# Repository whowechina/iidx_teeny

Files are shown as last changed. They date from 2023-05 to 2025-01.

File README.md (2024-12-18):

# Teeny IIDX - Beatmania IIDX controller

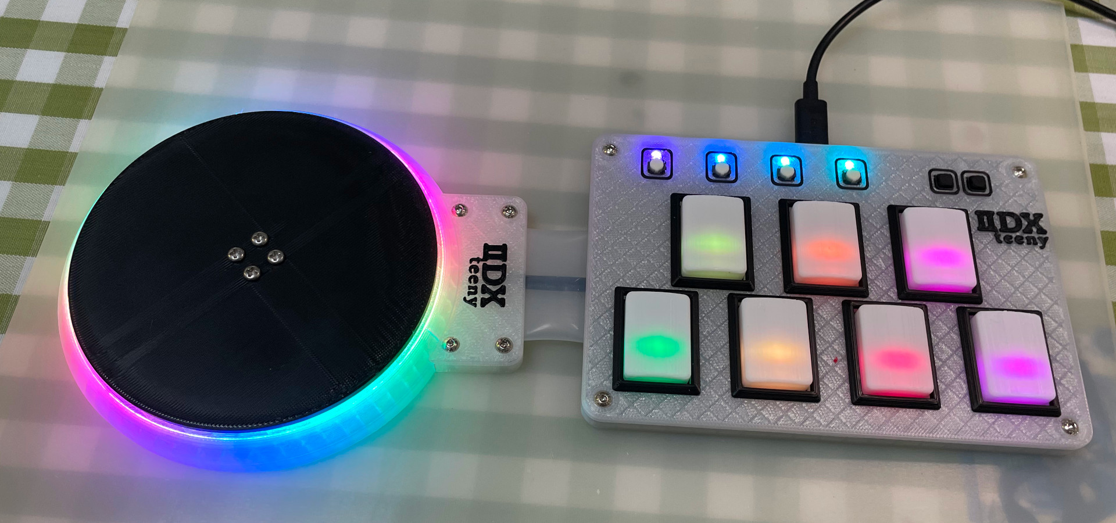
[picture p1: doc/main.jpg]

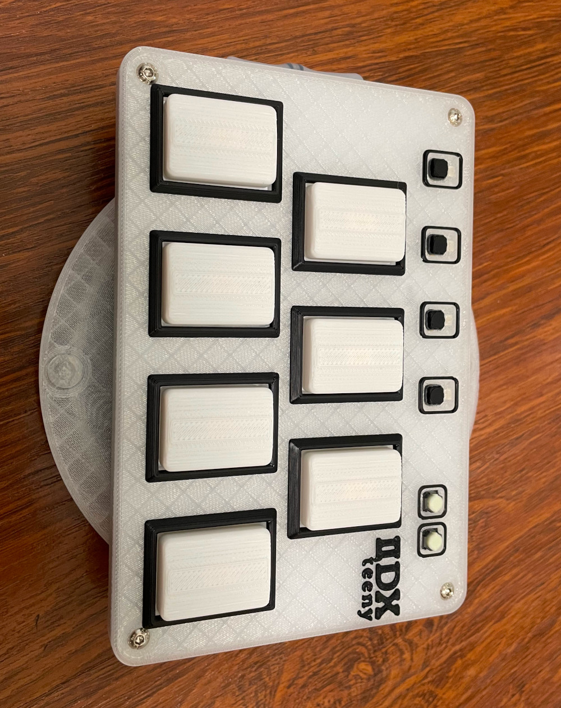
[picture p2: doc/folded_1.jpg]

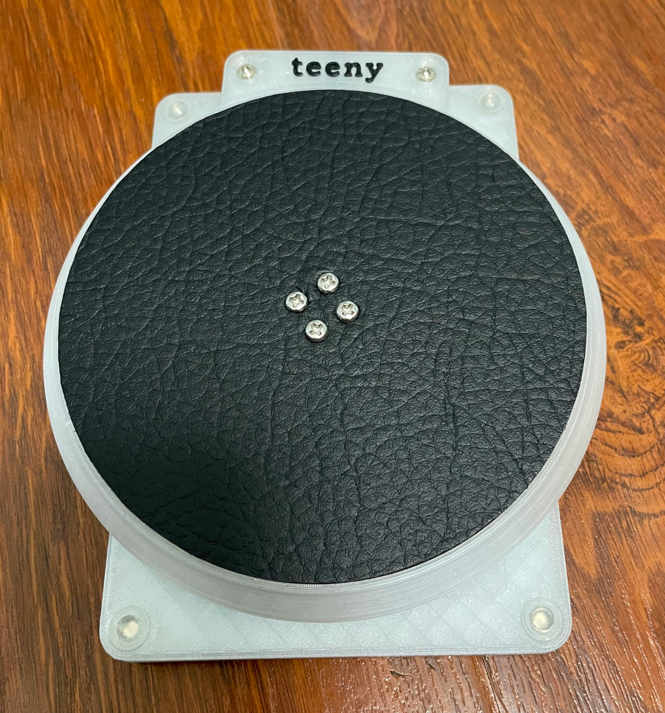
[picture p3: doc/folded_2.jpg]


# IMPORTANT NOTE
After a major refactor, I've merged this "IIDX Teeny" repository into the "IIDX Pico" repository and will no longer update this repository. Please refer to the "IIDX Pico" repository for guides and the latest updates.

https://github.com/whowechina/iidx_pico

This is the a small brother of my previous Pico IIDX controller. Both Pico IIDX and this Teeny IIDX share the same firmware which is in Pico IIDX repo.
<https://github.com/whowechina/iidx_pico>

Here's me playing Konami's Beatmania IIDX ultimate mobile with it. Yes, I'm a cat lover.
https://github.com/whowechina/iidx_teeny/assets/11623830/5aea28e7-6961-4d22-b5de-0fad74cdeacf

Features:
* It's thin, really really thin and foldable.
* HID lights, of course!
* Multiple turntable effects.
* Many live settings.
* All source files open.
* It's easier and more portable than IIDX Pico.

Thanks to many respectful guys/companies who made their tools or materials free or open source (KiCad, OpenSCAD, InkScape, Raspberry things). And also:
* RP_Silicon_KiCad: https://github.com/HeadBoffin/RP_Silicon_KiCad
* Switch_Keyboard_Kailh: https://github.com/kiswitch/keyswitch-kicad-library
* Type-C: https://github.com/ai03-2725/Type-C.pretty

## Notes
This project heavily relies on 3D printing, and skills to solder tiny components and thin cables.

## My Other Projects
You can check out my other cool projects.

         

* Popn Pico: https://github.com/whowechina/popn_pico
* IIDX Pico: https://github.com/whowechina/iidx_pico
* IIDX Teeny: https://github.com/whowechina/iidx_teeny
* Chu Pico: https://github.com/whowechina/chu_pico
* Mai Pico: https://github.com/whowechina/mai_pico
* Diva Pico: https://github.com/whowechina/diva_pico
* AIC Pico: https://github.com/whowechina/aic_pico
* Groove Pico: https://github.com/whowechina/groove_pico
* Geki Pico: https://github.com/whowechina/geki_pico
* Musec Pico: https://github.com/whowechina/musec_pico

## **Disclaimer** ##
I made this project in my personal time with no financial benefit or sponsorship. I will continue to improve the project. I have done my best to ensure that everything is accurate and functional, there's always a chance that mistakes may occur. I cannot be held responsible for any loss of your time or money that may result from using this open source project. Thank you for your understanding.

## About the License
It's CC-NC. So DIY for yourself and for your friend, don't make money from it. And plagiarism that doesn’t even dare to mention the original author is not acceptable. Plase note that pooling orders and group buying for raw materials is acceptable. Selling off any leftover components without profit is also acceptable.

If you're interested in some kind of commercial use, please contact me (Discord, QQ group, Wechat group or leave your contact in issue section).

## My Discord Invitation
https://discord.gg/M8f2PPQFEA

## HOW TO BUILD
### Turntable Materials
* 1x AS5600 hall angular sensor board set (23mm\*23mm)  
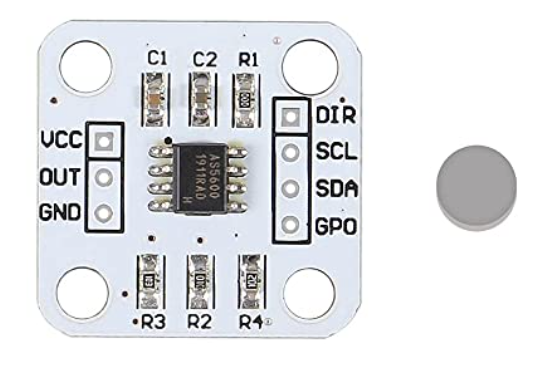
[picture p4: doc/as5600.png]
  
* 1x 6mm\*2mm magnet (must be radially magnetized), normally comes with the AS5600 board set, you can use one with different size of course, but you need to modify the 3D file.
* 1x 61804-2RS deep groove ball bearing (20x32x7mm), normally < 5US$;
* 1x WS2812B LED ring board, or RGB LED strip (recommended). Choose ones with dense LED arrangement (better if >=24 LEDs per board, or >90 LEDS per meter for LED strip);
* 6x M3*6mm screws (large flat head is better) and hex nuts.
* Non slip self-adhesive silicon pads (7-8mm diameter, also for Keyboard).  

### Keyboard Materials
* 1x Raspberry Pi Pico or Pi Pico W (if you need Bluetooth support).  
  https://www.raspberrypi.com/products/raspberry-pi-pico
* 7x Kailh Choc v1 key switches, to get better play feel, 7 of them should be linear (35gf to 50gf).  
  https://www.kailhswitch.com/mechanical-keyboard-switches/low-profile-key-switches/burnt-orange-switch.html  
* 6x Panasonic 6mm square tactile switch EVQP1K05M or a similar Alps one.  
  https://www3.panasonic.biz/ac/e/dl/catalog/index.jsp?series_cd=3473&part_no=EVQP1K05M
* 1x USB Type-C socket (918-418K2023S40001 or KH-TYPE-C-16P)
* 18x WS2812B-3528 RGB LEDs to light up the keys.
* 2x 0603 5.1kohm resistors for USB, (R20, R21).
* 2x 0603 0~20ohm resistors for light signals (R1, R2).
* 2x 0603 1-10kohm resistors for I2C pullup (R3, R4).
* 5x 0805 or 0603, 0.1 to 1uF capacitors.
* 4x M3*6mm screws and hex nuts to fix parts together.

### Connection for Foldable
* 2x silicon shielded cables with 4 core cables (about 25cm each), one for the RGB LEDs and one for the sensor.
* 1x silicon tube, outer diameter 27mm, inner diameter 25mm, so the wall thickness is 1mm.

### Step 1 - Buy
* Keyboard PCB  
  Just go [JLC](https://jlcpcb.com/) and make the order. Make sure the board thickness is **1.2mm**, it's very very important!

### Step 2 - 3D Print
#### Keyboard
Print with PLA transparent materials, 0.2mm layer, 4 walls, using 0.4mm nozzle.
* PCB bottom (teeny_bottom_P1|P2.stl, choose one according to your 1P or 2P choice).
* PCB top (teeny_top.stl)  
  Bambu Lab's AMS system is highly recommended, use PLA black for 3.0mm+ layers. So you'll have cool looking logo and key frames.

#### Turntable 
Again, print with 0.2mm layer, using 0.4mm nozzle, 5 walls. "Seam Position" should be set to "**Random**" in your slicer, not only it looks better, it makes the bearing-flange coupling smoother and tension distributed more evenly.  

* Base (teeny_tt.stl), PLA transparent.
* Bearing seat (teeny_bearing.stl), 20-60% fill, PLA white.
* Flange for disc (teeny_shaft.stl), 60% fill, PLA white.
* The disc (teeny_disc.stl), 60% fill, all fill patterns should be set to "Concentric".

#### Button keycaps  
* Print upside down, with easy-to-remove support materials.  
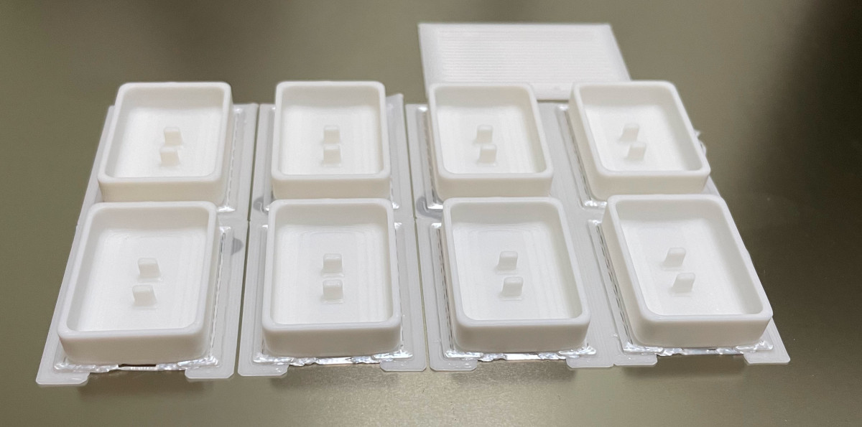
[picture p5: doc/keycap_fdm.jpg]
  

### Other Steps
It's similar to my previous Pico IIDX project, just read the documentation there.
<https://github.com/whowechina/iidx_pico>

But there're something you need to pay attention:
* On Teeny's PCB, there are 2 sets of soldering pads, 1 set is for AS5600, the other is for the WS2812 LED ring.
  * J1 is for LED, 5V is the power, L is LED signal, G is ground.
  * J2 is for AS5600, 3V is the power (actually 3.3V), S is I2C SCL, D is I2C SDA, G is ground.
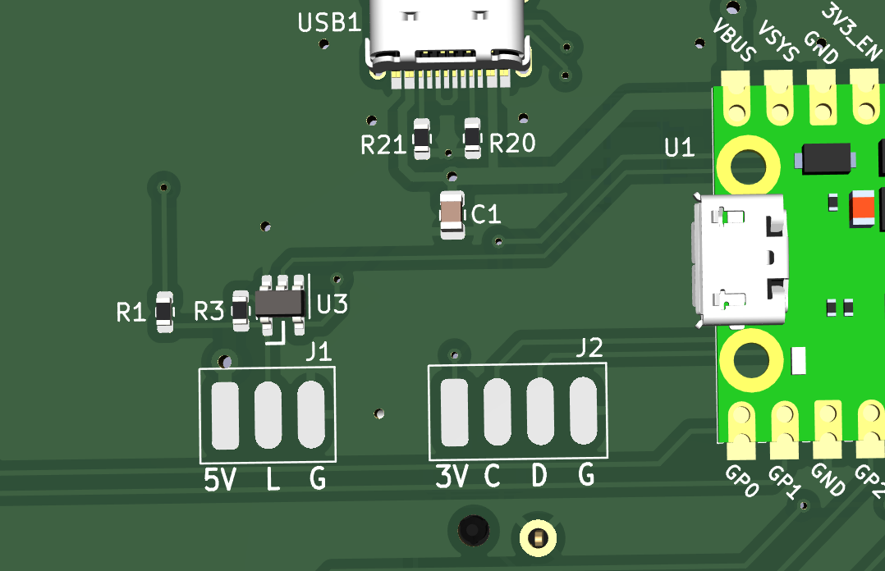
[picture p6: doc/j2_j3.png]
  
  * Please use two seperate cables to wire LED and AS5600, both (or at least one) should be shielded to prevent crosstalk interference.
  * Choose thin/soft cables, so they can fit. Get ultra thin USB cable or extract daughter cables from abandoned HDMI cables. 2mm diameter is the best.
  * R3, R4 are optional, if turntable (I2C) is not working properly, you may try use them.
  * There's a nice manual in IIDX Pico's repo, under doc folder. Follow the manual to set AS5600 to I2C mode and then do your LED ring setup.  
  <https://github.com/whowechina/iidx_pico/tree/main/doc/Firmware_manual.pdf>
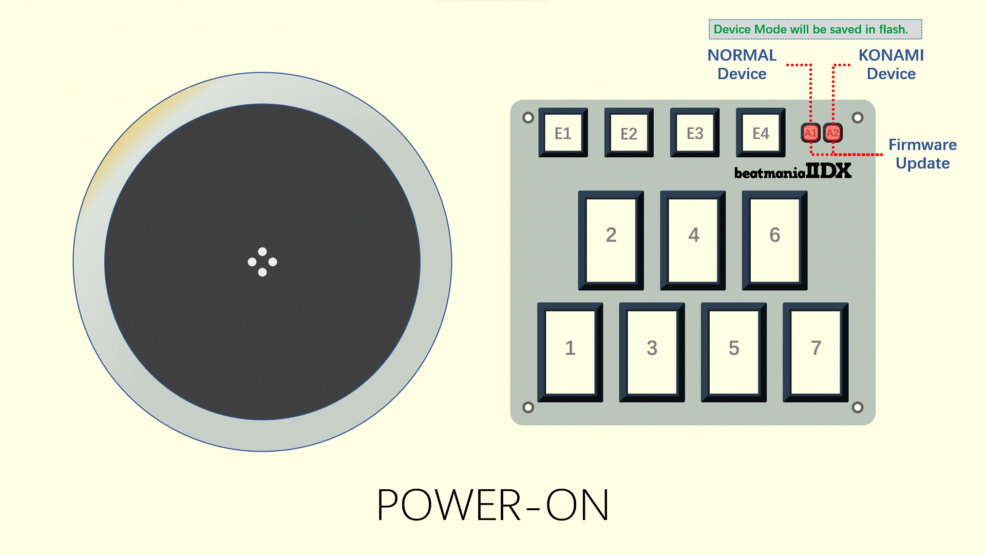
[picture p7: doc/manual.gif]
  

#### About the License
It's CC-NC. So diy for yourself and for your friend, don't make money from it.

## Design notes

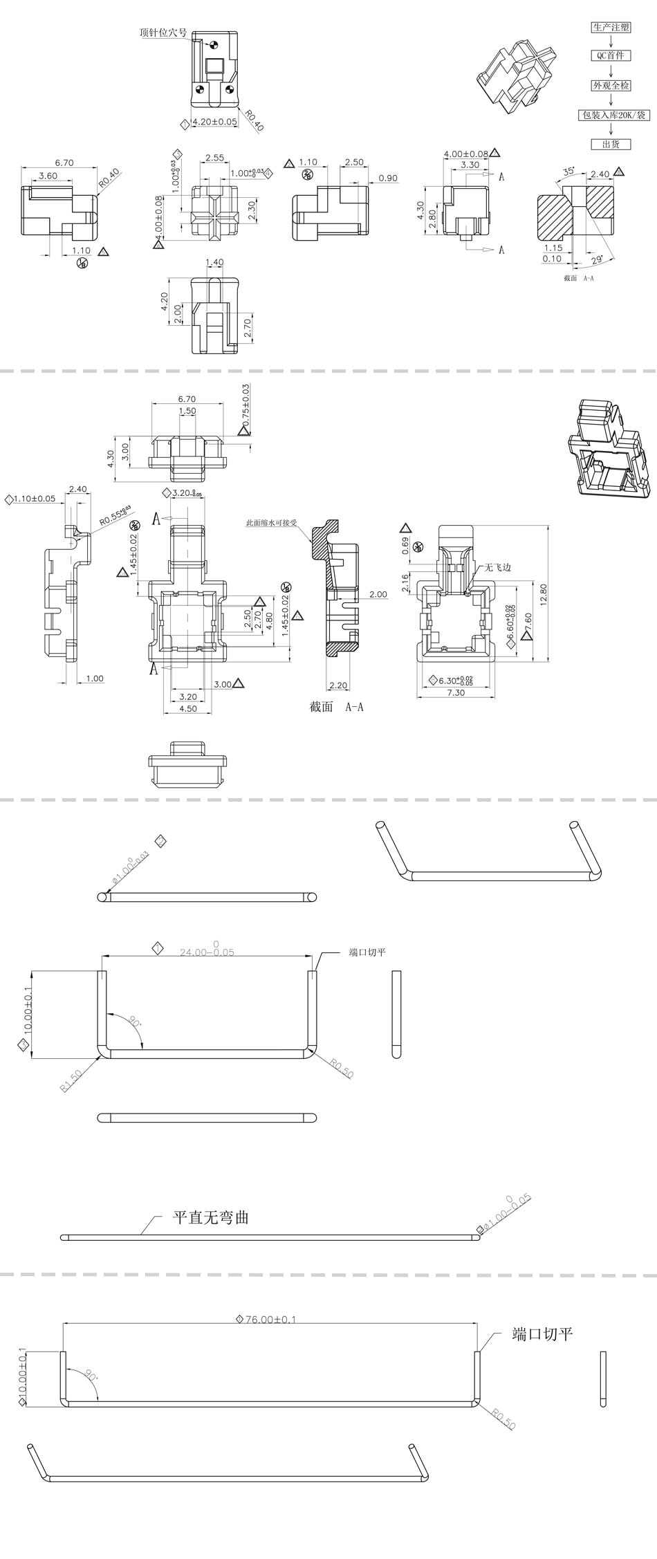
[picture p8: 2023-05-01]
cad/kailh-choc-stibilizer-4.jpg

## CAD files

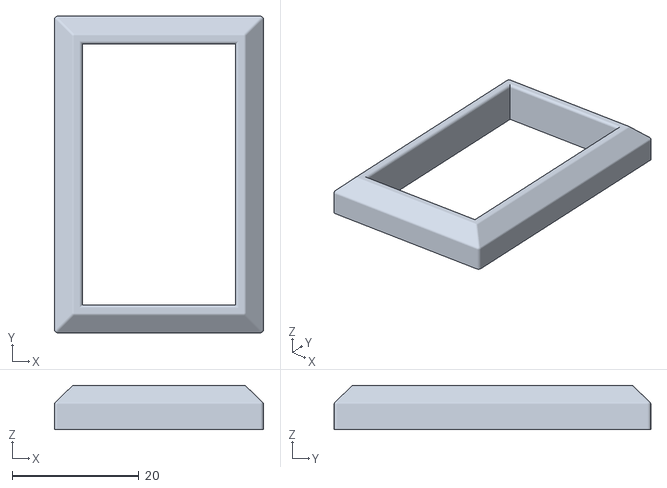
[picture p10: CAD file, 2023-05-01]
cad/keycap_frame_main.stl
33.0 x 50.0 x 7.00

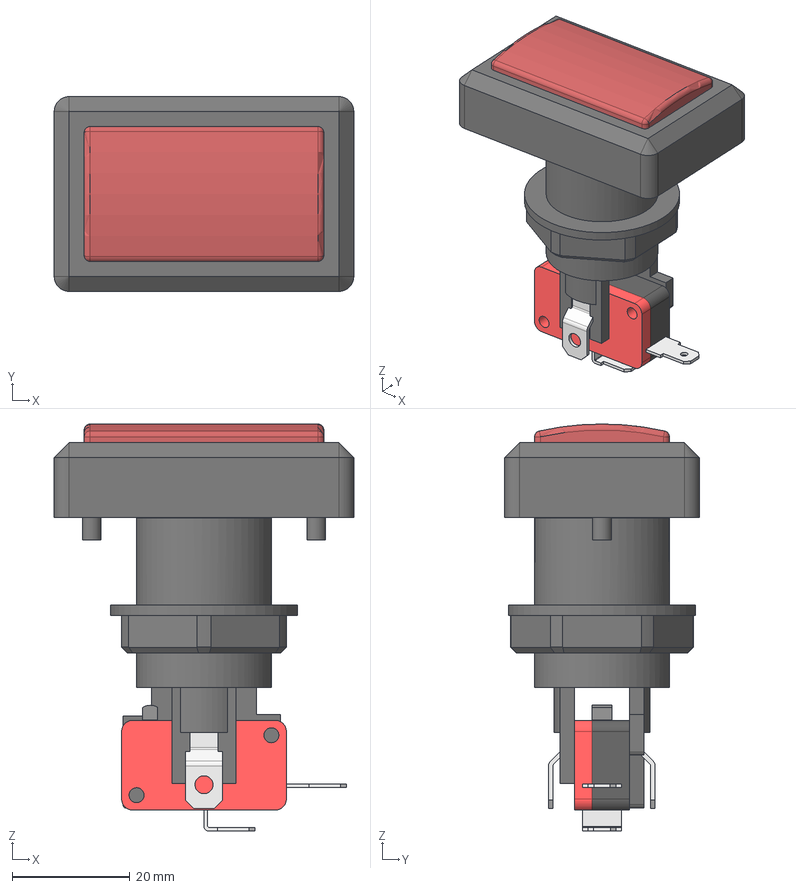
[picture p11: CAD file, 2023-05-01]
PCB/Keyboard/3dmodels/Credit Button Assy (Groovy).step
50.8 x 33.0 x 69.0 mm
Button
Nut
Switch

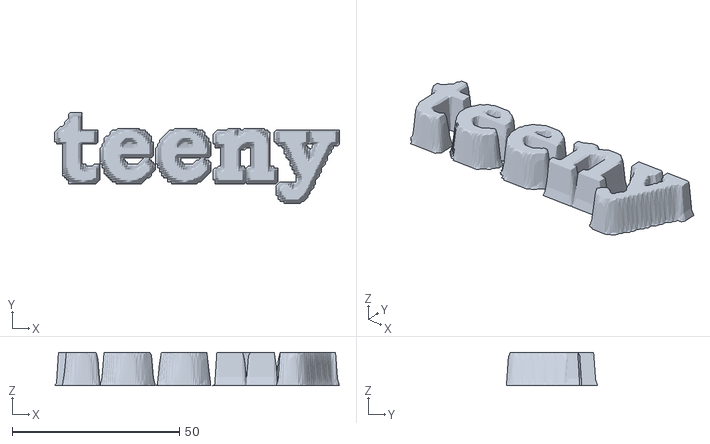
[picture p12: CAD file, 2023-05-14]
cad/teeny_only_logo.stl
85.2 x 27.3 x 10.0

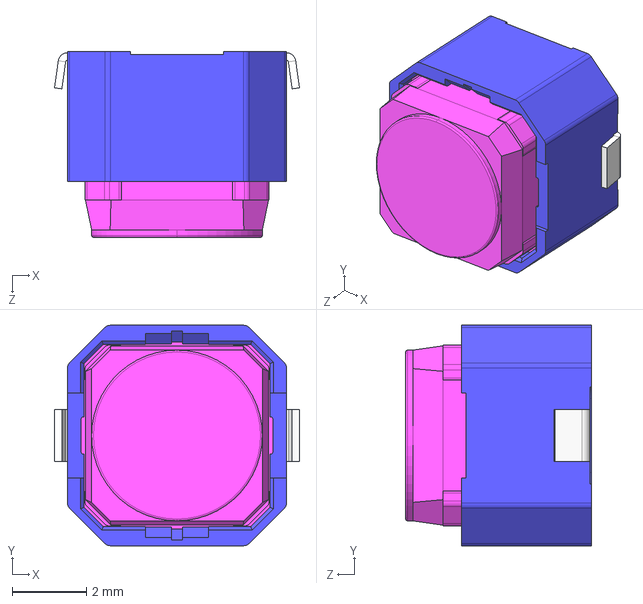
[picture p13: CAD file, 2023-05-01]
PCB/Keyboard/3dmodels/SKPMAM.STEP
6.60 x 5.94 x 5.00 mm

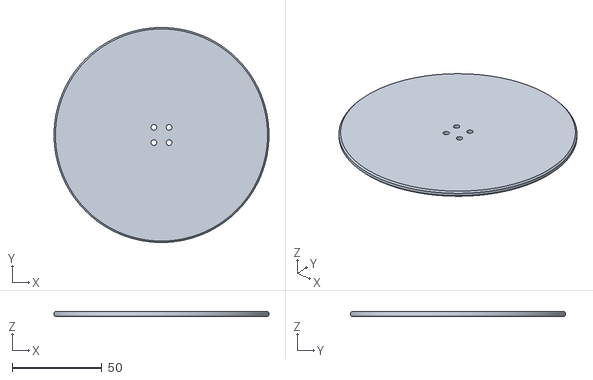
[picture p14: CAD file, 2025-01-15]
Production/3DPrint/Turntable Teeny - Disc.stl
120.0 x 120.0 x 3.00

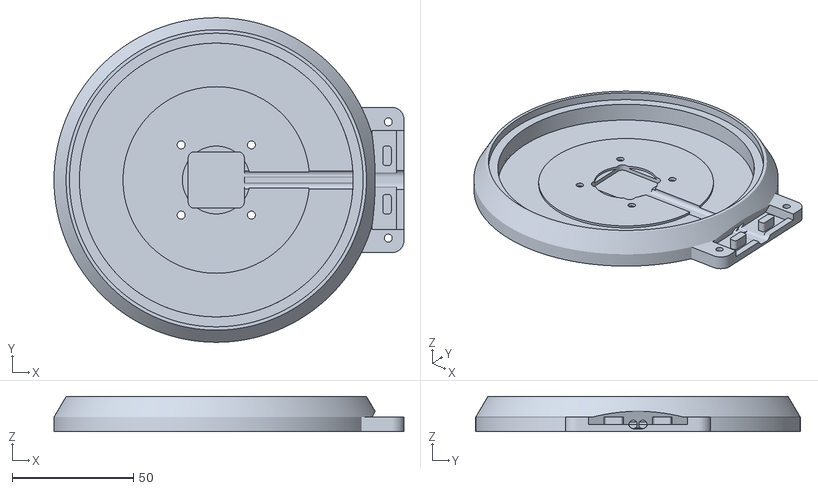
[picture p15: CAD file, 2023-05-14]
cad/teeny_tt.stl
144.5 x 134.0 x 14.5

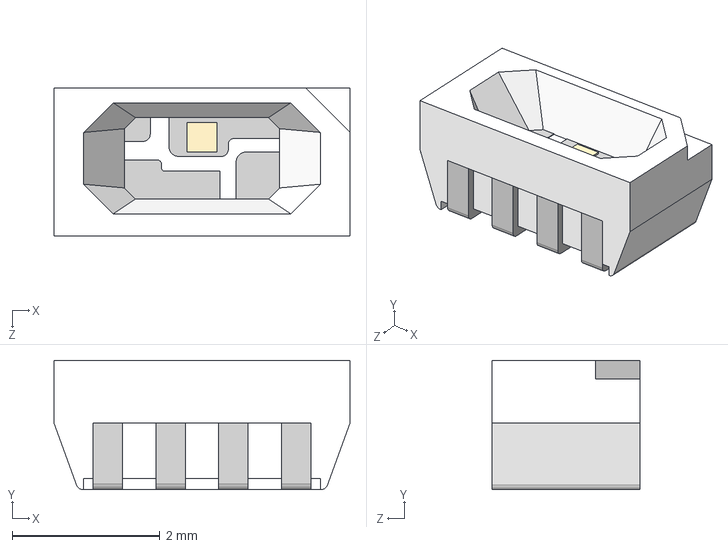
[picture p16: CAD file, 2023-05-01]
PCB/Keyboard/3dmodels/User Library-WS2812-4020.step
4.00 x 1.75 x 2.00 mm

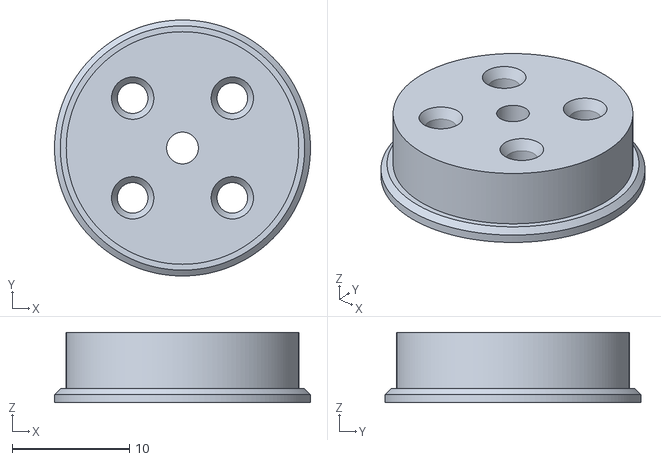
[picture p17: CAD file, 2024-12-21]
Production/3DPrint/Turntable - Magnet Seat.stl
21.8 x 21.8 x 6.00

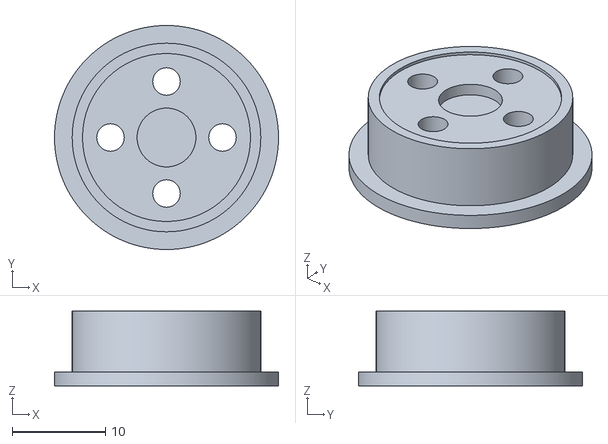
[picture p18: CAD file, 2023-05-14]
cad/teeny_shaft.stl
24.0 x 24.0 x 8.00

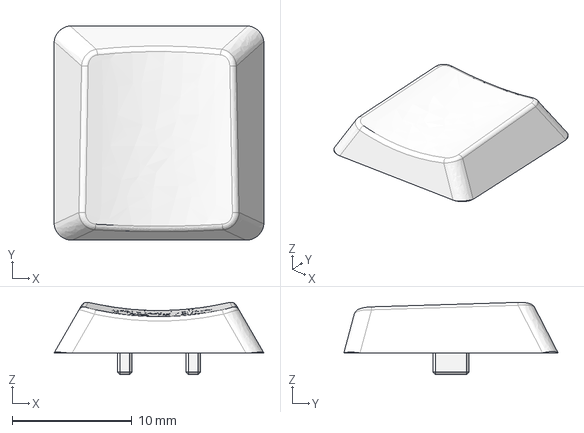
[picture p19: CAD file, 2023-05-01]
PCB/Keyboard/3dmodels/Kailh LP Choc PC Keycap.step
17.5 x 17.9 x 6.03 mm

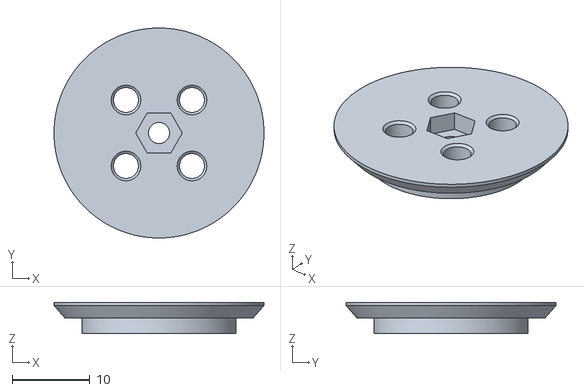
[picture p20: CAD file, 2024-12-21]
Production/3DPrint/Turntable - Disc Seat.stl
27.0 x 27.0 x 4.00

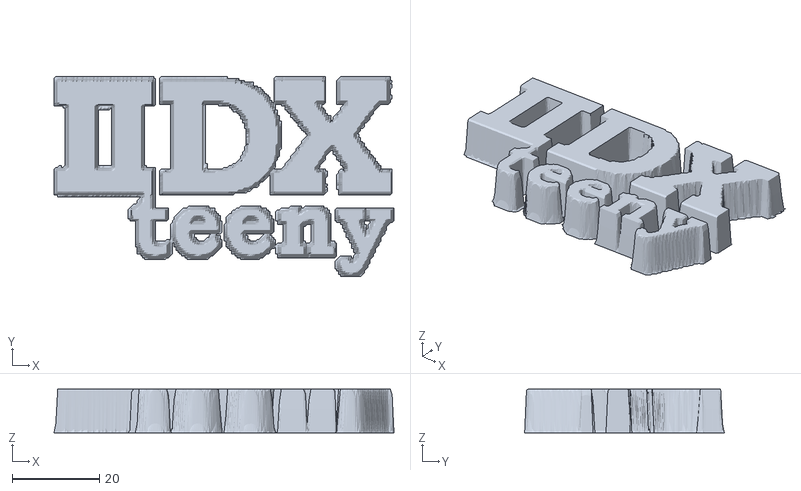
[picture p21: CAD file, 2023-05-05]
cad/iidx_teeny_logo.stl
78.0 x 45.8 x 10.0

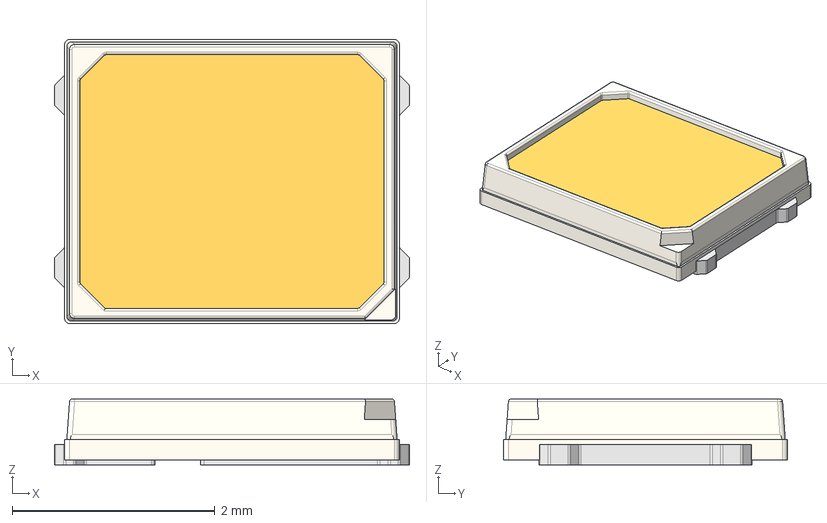
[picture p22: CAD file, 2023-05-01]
PCB/Keyboard/3dmodels/J 2835.step
3.50 x 2.80 x 0.65 mm

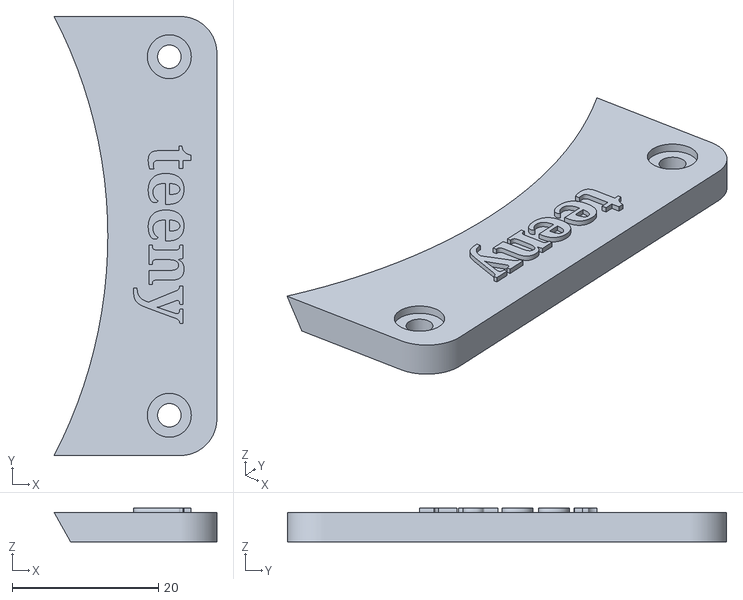
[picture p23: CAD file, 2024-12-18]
Production/3DPrint/Turntable Teeny - Banner.stl
22.2 x 60.0 x 4.60

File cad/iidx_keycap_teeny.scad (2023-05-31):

w=20;
h=28;
r=1.2;
solid=1.1;
zoff=-1.3;

gap_r = 0.18; // radius of round corner in cross
stem_l = 4.85; // socket stem length
stem_d = 5.6; // socket stem diameter

translate([0,0,0]) {
  cap();
  *stems(); // Choc V1, SLA
  stems(v1=true); // Choc V2, SLA/FDM
}

%union() {
  mark([2.5,0.3,0],2.1,"purple");
  mark([0,0,0],6.1,"red");
}

module mark(offset=[0,0,0],h=5.5,c="red") {
  translate(offset) {
    color(c) hull() {
      cylinder(d=0.1,h=h,$fn=32);
      cylinder(d=1,h=0.1,$fn=64);
    }
    color("white") cylinder(d=0.1,h=h+5,$fn=64);
  }
}

module stems(v1=true,sla=true) {
  if (v1) {
    // choc v1
    translate([0,0,1.8]) rotate([0,0,0]) color("cyan") {
      choc_stem([0,2.85,0],4.5);
      choc_stem([0,-2.85,0],4.5);
    }
  } else {
    // choc v2
    translate([0,0,1.8]) {
      stab_stem([0,0,0],stem_l-1.8,5.48,1.31,4.02,4.02,5);
    }
  }
}

module cap() {
  difference() {
    body(w,h,r);
    translate([0,0,-solid]) body(w-2*solid,h-2*solid,r);
  }
}

module body(w,h,r) {
  difference() {
    translate([0,0,zoff-0.5]) minkowski() {
      intersection() {
        ww=w-2*r;
        hh=h-2*r;
        translate([-ww/2,-hh/2,0]) rcube(ww,hh,20,0.7,$fn=64);
        translate([0,0,-5]) resize([50,39,26]) rotate([90,0,0]) cylinder(d=10,h=10,center=true,$fn=256);
      }
      sphere(r=r,$fn=48);
    }
    translate([-50,-50,-10]) cube([100,100,10]);
  }
}

module rcube(x,y,z,r) {
  hull() {
    translate([r,r,0]) cylinder(r=r,h=z);
    translate([x-r,r,0]) cylinder(r=r,h=z);
    translate([r,y-r,0]) cylinder(r=r,h=z);
    translate([x-r,y-r,0]) cylinder(r=r,h=z);
  }
}

module choc_stem(offset=[0,0,0],h) {
  translate([0,0,6.4+zoff-h]) translate(offset) {
    translate([-1.5,-0.6,0.3]) cube([3,1.2,h-0.4]);
    hull() {
      translate([-1.5,-0.6,0.3]) cube([3,1.2,0.1]);
      translate([-1.2,-0.5,0.0]) cube([2.4,1,0.1]);
    }
    hull() {
      translate([-1.5,-0.6,h-1.2]) cube([3,1.2,0.1]);
      translate([-2.5,-1.5,h-0.1]) cube([5,3,0.1]);
    }
  }
}

module stab_stem(offset=[0,0,0], length, d, gap_w, gap_h1, gap_h2,dig) {
  translate([0,0,zoff]) translate(offset) difference() {
    translate([0,0,5.2-length]) {
      cylinder(d=d,h=length,$fn=64);
      translate([0,0,length-0.01]) cylinder(d1=d,d2=8,h=1,$fn=64);
      translate([0,0,-0.4]) cylinder(d1=d-0.7,d2=d,h=0.401,$fn=64);
    }
    translate([0,0,3.5-length]) difference() {
      l=length+1;
      union() {
        translate([0,0,l/2]) color("green") cube([gap_h1,gap_w,dig], center=true);
        translate([0,0,l/2]) color("red") cube([gap_w,gap_h2,dig], center=true);
        translate([0,0,l/2]) cube([gap_w+gap_r*2,gap_w+gap_r*2,dig], center=true);
      }
      
      r = gap_w/2 + gap_r;
      for (i=[-1,1]) {
        for (j=[-1,1]) {
          translate([i*r,j*r,-1]) cylinder(r=gap_r,h=6,$fn=24);
        }
      }
    }
  }
}

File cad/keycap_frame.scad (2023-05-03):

//teeny_button();
//main_button();
//aux_button();

module teeny_button() {
  frame(21.2, 29.2, 2.8, 0.8, 0.5, 3, 1.5, 0);
}

module main_button() {
  frame(24.2, 41.2, 4.4, 1.8, 0.5, 3.3, 1.5, 0);
}

module aux_button() {
  frame(18, 18, 3.4, 1.5, 1.5, 3.5, 1.5, 0);
}

module frame(w, h, x1, x2, d1, d2, sm, lift)
{
  difference() {
    minkowski() {
      difference() {
        color("brown") hull() {
          framecube(w,h,d1,x1,-sm,lift);
          framecube(w,h,d2,x2,-sm,lift);
        }

        color("blue") {
          translate([0,0,-1]) framecube(w,h,d2+2,0,sm,lift);
        }
      }
      sphere(d=sm,$fn=48);
    }
    translate([0,0,-5]) cube([100,100,10],center=true);
  }
}

module framecube(w,h,d,x,sm,lift) {
  translate([0,0,d/2]) cube([w+x*2+sm,h+x*2+sm,d+lift*2],center=true);
}

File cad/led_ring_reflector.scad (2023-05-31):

difference() {
  cylinder(d1=94,d2=108,h=5.8,$fn=200);
  translate([0,0,-0.1]) cylinder(d1=90,d2=103,h=6,$fn=200);
}

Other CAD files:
PCB/Keyboard/3dmodels/iidx_keycap_main_step.stp
cad/iidx_keycap_teeny.stl
PCB/Keyboard/3dmodels/WS2812B.step
Production/3DPrint/Keyboard Teeny - Panel.stl
cad/teeny_bottom.scad
PCB/Keyboard/3dmodels/EVQ-P1D05M.stp
PCB/Keyboard/3dmodels/Magnetic Pogo Connector 5 Pin (F).STEP
PCB/Keyboard/3dmodels/Magnetic Pogo Connector 5 Pin (M) - 副本.STEP
PCB/Keyboard/3dmodels/Magnetic Pogo Connector 5 Pin (Type 1).STEP
PCB/Keyboard/3dmodels/Magnetic Pogo Connector 5 Pin (Type 2).STEP
PCB/Keyboard/3dmodels/Magnetic Pogo Connector 5 Pin (Type 3).STEP
PCB/Keyboard/3dmodels/Magnetic Pogo Connector 5 Pin (Type 4).STEP
PCB/Keyboard/3dmodels/SMD WS2812B-3535.step
PCB/Keyboard/3dmodels/SW_Hotswap_Kailh_Choc_V1.stp
PCB/Keyboard/3dmodels/SW_Hotswap_Kailh_MX.stp
PCB/Keyboard/3dmodels/SW_Kailh_Choc_V1.stp
PCB/Keyboard/3dmodels/Tact Switch 4.5mm SMT.step
PCB/Keyboard/3dmodels/User Library-PTS645SL95SMTR92-LFS.STEP
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

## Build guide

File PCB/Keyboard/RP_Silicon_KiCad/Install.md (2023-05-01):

# Install KiCad libraries

## Manage Symbol Libraries

Accessed from the Preferences menu, add a new line with the +, give it a name and use the folder icon to point to the directory/folder where you have KiCadLibraries.

Manage Symbol Libraries screen shot


## Manage Footprint Libraries

Ditto! Accessed from the Preferences menu, add a new line with the +, give it a name and use the folder icon to point to the directory/folder where you have KiCadLibraries.

Manage Footprint Libraries screen shot


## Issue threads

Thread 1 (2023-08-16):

Wiring Diagram request

rain2usa, 2023-08-16:
Hello.  I am making this controller and have all the parts (I think).  I tried following your directions, but your iidx_pico used connectors and I can't follow how your teeny is wired.  Could you provide a wiring diagram from the AS5600 (do we need the REF3030 for the teeny?  It's not listed in the parts) to the keyboard?  I think I can do the rest after that.  Thank you.
(Oh, and one more thing. Could you tell me where you bought the silicon tube?  I can't find one anywhere)

whowechina, 2023-08-16:
No, you don’t need ref3030, as in teeny, as5600 is powered using 3.3V directly from pick, check the soldering pads there. 4 wires for the as5600, 3 wires for the led ring. Remember the wire shield is important as led and i2c they interfere with each other. 在 2023年8月16日，10:34，rain2usa ***@***.***> 写道：
Hello.  I am making this controller and have all the parts (I think).  I tried following your directions, but your iidx_pico used connectors and I can't follow how your teeny is wired.  Could you provide a wiring diagram from the AS5600 (do we need the REF3030 for the teeny?  It's not listed in the parts) to the keyboard?  I think I can do the rest after that.  Thank you.

—Reply to this email directly, view it on GitHub, or unsubscribe.You are receiving this because you are subscribed to this thread.Message ID: ***@***.***>

rain2usa, 2023-08-16:
Thank you for the quick reply, but I am still lost a little. My apologies; I know how to build projects but I am not familiar with Pico enough to know where the wires "should" go in this setup.  I can program them well enough though.  I have made a template below.  Would you be able to edit it and tell me where all the wires go?  I see there are 2 shielded cables coming out of the turntable as well.  If you could show how each are connected, I would appreciate it.
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

rain2usa, 2023-08-16:
ok, I feel a little stupid.  I didn't notice the pads on the bottom of the Keyboard PCB. :(  Does this look somewhat right?  I'm assuming I'm still modifying the AS5600 by removing the resistor R4 to make "OUT" work like in the Pico build?  And I don't know where C and D pads go to.
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

whowechina, 2023-08-16:
Yes exactly!
R4 mod is not required as teeny uses i2c communication.

Silicon cables with shield is the best for this, they're flexible. They
often called high temperature ultra soft shielded cables.

rain2usa ***@***.***> 于 2023年8月16日周三 上午11:37写道：

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

whowechina, 2023-08-16:
C means SCL (clock), D means SDA (data).

WHowe China ***@***.***> 于 2023年8月16日周三 上午11:46写道：

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

rain2usa, 2023-08-16:
Thank you so much for confirming.  I'll post photos when it is complete.  Where did you buy the 27mm silicone tube?  I looked for them at local stores and couldn't find anything close with 1mm walls.

whowechina, 2023-08-16:
I bought from Taobao, l guess you can find some from Aliexpress.
If you can't get them, tough cloth with some sewing or stampling works too.
It's just a flexible connection.

rain2usa ***@***.***> 于 2023年8月16日周三 上午11:59写道：

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

rain2usa, 2023-08-20:
Good Evening/Morning.  I am almost done soldering the Keyboard, but when I put the Pico on the board, 3 pads don't exist.  Where do these 3 (SWDIO, SWCLK, and the middle pad) wire up to?
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

rain2usa, 2023-08-20:
I seem to answer these questions myself after I submit my comments. :(  The W changed the layout and I found the debug pins in the middle of the board.  I'll wire them up manually.  I think there's enough pad to do that.
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

whowechina, 2023-08-21:
You don't need to solder those 3 debug pins, they're not used by teeny.
Also, don't solder R1 to R3, they're for other test option.
R20/21 are 5.1kohm.
Capacitors can be 0.1-1uF or even leave them absent.

rain2usa ***@***.***> 于 2023年8月16日周三 上午10:34写道：

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

rain2usa, 2023-08-23:
Thank you.  All PCB solder is complete.  Bearing is complete. But LED strip is an issue.  Do you have a link for the WS2812B LED Strip you used for the Teeny Turntable (alibaba or aliexpress is fine)?  There's only 8mm of vertical space and all the ones I'm finding are 10mm minimum, including the one I have on hand.

whowechina, 2023-08-23:
Hi,
Use keyword "ultra-thin ws2812 led strip/belt" maybe? Or use "4mm" instead
of "ultra-thin". Another choice would be circular ws2812 led pcb, choose
one that fits.
You can test the teeny without the led.
Please note that l have a pdf/ppt manual in the repo.

rain2usa ***@***.***> 于 2023年8月23日周三 上午11:47写道：

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

rain2usa, 2023-08-24:
I have completed majority of the wire soldering.  I was able to program it with your firmware.  Windows detects button presses but None of the LEDs turn on.  Any ideas why I can't get them to turn on on the Keyboard?
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

whowechina, 2023-08-24:
For button LEDs, check:
1. U2 level shifter (carefully check the soldering of pins), or you can
remove it and use a 10-20 ohm resister to repalce it, the nearby resister
footprint).
2. Color theme configuration (see ppt manual)
3. LED orientation and pinout matches to my footprint.

Normally they light up when pressed.

Other issues:
Shiled cable, the shield itself should connect to ground.But you can try
first, if there's inteference between tt led and tt as5600, you need to do
what l said.

rain2usa ***@***.***> 于 2023年8月24日周四 上午9:47写道：

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

whowechina, 2023-08-24:
I'm using Pico W on my own and very first teeny.
Button leds are ws2812 based, means they are daisy chained. If the first
one doesn't work, the followers won't work too. So only check the first
one. The fist one is Button 2 (upper left one of main 7 buttons).

You noticed teeny was running from PC side joystick test program and
buttons/as5600 are working correctly?

Leds are driven by core 2, iirc as5600 is polled on core 2 as well, if the
core2 somehow fails, they won't light up.

Are you in C&S discord server?

rain2usa ***@***.***> 于 2023年8月25日周五 上午12:31写道：

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

rain2usa, 2023-08-25:
I will check the first LED and let you know.

The as5600 is not functioning though in the PC Joystick Test program.  All the buttons work fine.  I was able to map them for retroarch and they worked. Nothing is recognizing the TT yet.

Worse case is I try to pull off that Pico and put a different one in.  That's going to be difficult with the solder on the bottom as well.

Not familiar with the C&S one.  I'm in many different servers, but not that one.

whowechina, 2023-08-25:
No, don't swap the Pico W, it should be fine.

Fix AS5600 first, note you need to change sensor mode to digital first.
Check the ppt/pdf manual, you need to blind try as leds not working.

rain2usa ***@***.***> 于 2023年8月25日周五 上午8:33写道：

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

whowechina, 2023-08-25:
You can find me on Discord Whowechina#0000.

rain2usa ***@***.***> 于 2023年8月25日周五 上午8:33写道：

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

rain2usa, 2023-08-25:
You have a discord invite link to that C&S server?
I blindly switched the as5600 into digital mode and it does indeed work!  The joystick test shows it going from bottom left to top right diagonally.  I'll swap the LED with a new one to see if that really is the root cause.

rain2usa, 2023-08-25:
I changed out the first LED and still the same result.  Voltage is there.  It's just not lighting up for some reason.  Just to be sure we're talking about the same LED, this is the one I swapped out.
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

whowechina, 2023-08-25:
send dm or invitation to me on discord。whowechina#0000在 2023年8月25日，10:44，rain2usa ***@***.***> 写道：
I changed out the first LED and still the same result.  Voltage is there.  It's just not lighting up for some reason.  Just to be sure we're talking about the same LED, this is the one I swapped out.

—Reply to this email directly, view it on GitHub, or unsubscribe.You are receiving this because you commented.Message ID: ***@***.***>

whowechina, 2023-08-25:
Cons&Stuff:
https://discord.gg/AjWPrKXx

rain2usa, 2023-09-03:
All remaining issues have been resolved.  Controller has been built; LEDs work, FW loads. You must set the TT to I2C to get it to recognize in Windows.  Make sure to set the Key Themes to turn on the LEDs if it's not on upon first boot (same with TT).  This will show you the mode you're in in the Firmware.  One issue was the firmware but that got fixed, so there should be no further issues with it.  (Photo below showing completed controller using Fireblade TT theme).  (don't have a Bambu printer so it was printed with just translucent and white filament).
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

Closed 2023-09-03.

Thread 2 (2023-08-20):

Resistor/Capacitor List Confirmation

rain2usa, 2023-08-20:
The teeny main page seems to be missing components and wrong quantities.  Could you please confirm the values?

C1 - C5 - 1uf 0805 caps
R20, R21 - 5k1 0603 resistor (main page shows 1)
R1 - R3 - Not sure as it's not listed on main page.  Schematics says 10.  Does this mean 10ohms? 0603 package?

I'd appreciate what you can provide. Thank you.

rain2usa, 2023-08-24:
This was resolved in the Wiring Diagram issue thread.

Closed 2023-08-24.

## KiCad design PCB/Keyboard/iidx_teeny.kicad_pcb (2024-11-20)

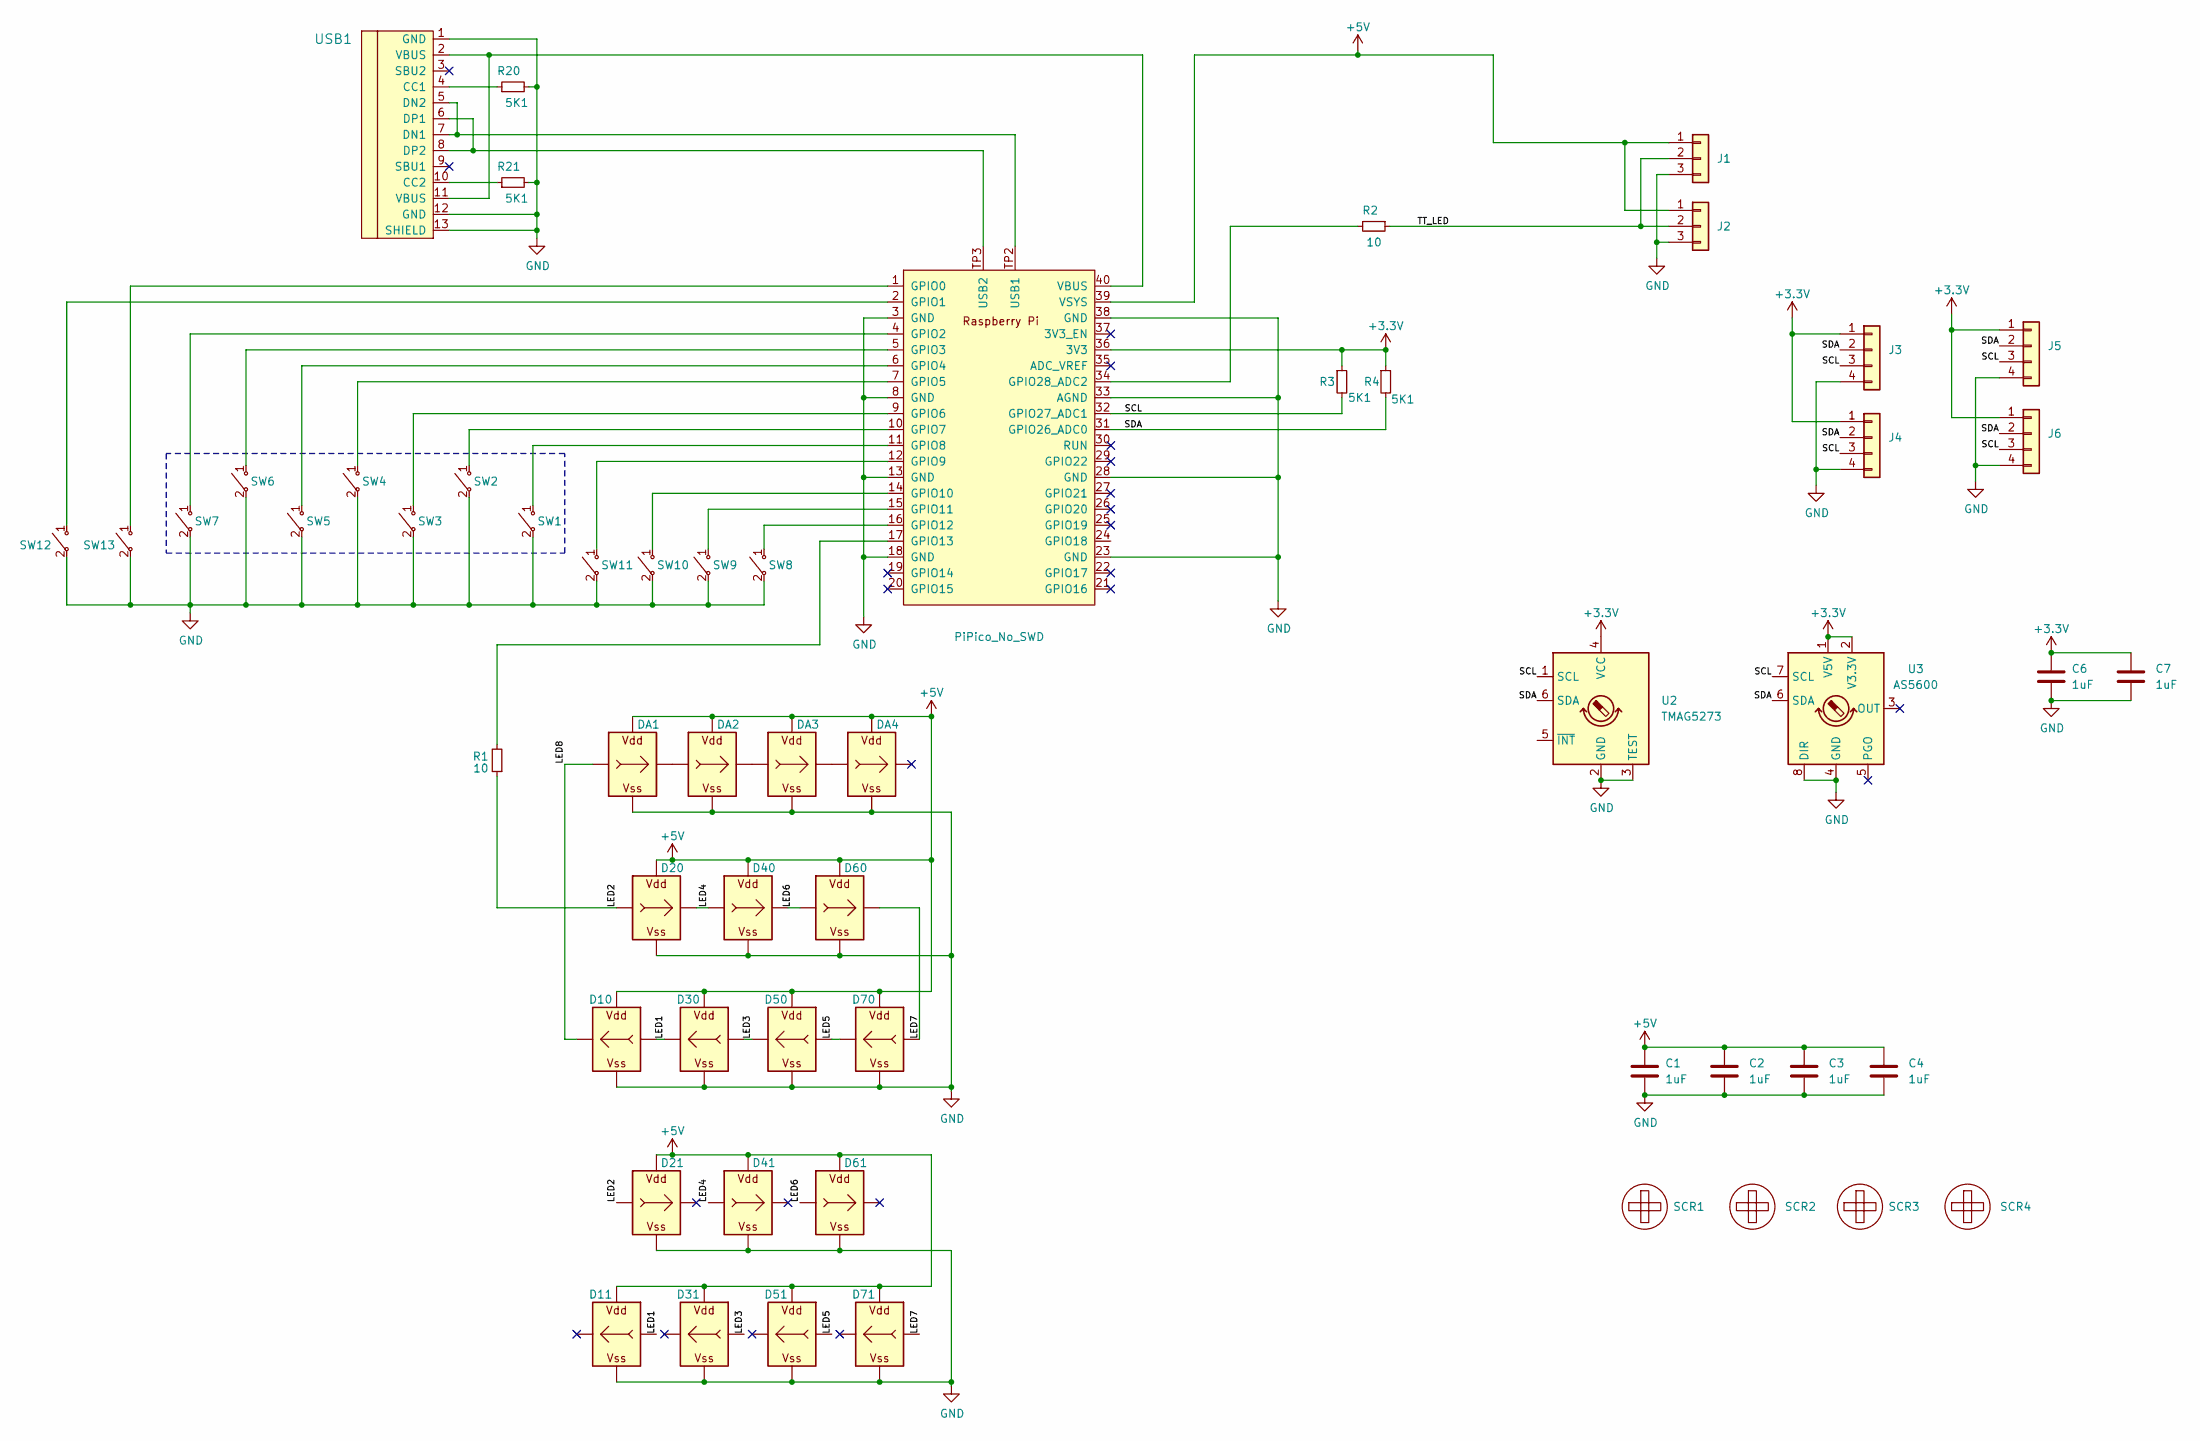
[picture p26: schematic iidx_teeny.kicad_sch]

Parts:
C1, C2, C3, C4, C6, C7: 1uF; C_0603_1608Metric_Pad1.08x0.95mm_HandSolder
D10, D11, D20, D21, D30, D31, D40, D41, D50, D51, D60, D61, D70, D71: WS2812B_Unified; WS2812B-2835
DA1, DA2, DA3, DA4: WS2812B_Unified; WS2812B-2835
J1, J2: RGB; SH1.0_3P_Solder_Combo
J3, J4: Spin; SH1.0_4P_Solder_Combo
J5, J6: Spin; P2.0_4P_Solder
R1, R2: 10; R_0603_1608Metric_Pad0.98x0.95mm_HandSolder; LCSC C23186
R3, R4, R20, R21: 5K1; R_0603_1608Metric_Pad0.98x0.95mm_HandSolder; LCSC C23186
SCR1, SCR2, SCR3, SCR4: ScrewHole; MountingHole_3.2mm_M3
SW1, SW2, SW3, SW4, SW5, SW6, SW7: SWITCH_SPST; SW_Kailh_Choc_V1V2_1.00u_LED
SW8, SW9, SW10, SW11, SW12, SW13: SWITCH_SPST; EVQP1K05M
U1: PiPico_No_SWD; RPi_Pico_SMD_Pins_No_SWD_No_Text
U2: TMAG5273; TSOT-23-6_HandSoldering
U3: AS5600; SOIC-8_3.9x4.9mm_P1.27mm
USB1: U262-161N-4BVC11; HRO-TYPE-C-31-M-12-Assembly; LCSC C319148

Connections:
+3.3V: C6.1, C7.1, J3.1, J4.1, J5.1, J6.1, R3.1, R4.1, U1.36 (3V3), U2.4 (VCC), U3.1 (V5V), U3.2 (V3.3V)
+5V: C1.1, C2.1, C3.1, C4.1, D10.V (VDD), D11.V (VDD), D20.V (VDD), D21.V (VDD), D30.V (VDD), D31.V (VDD), D40.V (VDD), D41.V (VDD), D50.V (VDD), D51.V (VDD), D60.V (VDD), D61.V (VDD), D70.V (VDD), D71.V (VDD), DA1.V (VDD), DA2.V (VDD), DA3.V (VDD), DA4.V (VDD), J1.1, J2.1, U1.39 (VSYS)
/LED1: D10.I (In), D11.I (In), D30.O (Out)
/LED2: D20.I (In), D21.I (In), R1.1
/LED3: D30.I (In), D31.I (In), D50.O (Out)
/LED4: D20.O (Out), D40.I (In), D41.I (In)
/LED5: D50.I (In), D51.I (In), D70.O (Out)
/LED6: D40.O (Out), D60.I (In), D61.I (In)
/LED7: D60.O (Out), D70.I (In), D71.I (In)
/LED8: D10.O (Out), DA1.I (In)
/SCL: J3.3, J4.3, J5.3, J6.3, R3.2, U1.32 (GPIO27_ADC1), U2.1 (SCL), U3.7 (SCL)
/SDA: J3.2, J4.2, J5.2, J6.2, R4.2, U1.31 (GPIO26_ADC0), U2.6 (SDA), U3.6 (SDA)
/TT_LED: J1.2, J2.2, R2.1
GND: C1.2, C2.2, C3.2, C4.2, C6.2, C7.2, D10.G (VSS), D11.G (VSS), D20.G (VSS), D21.G (VSS), D30.G (VSS), D31.G (VSS), D40.G (VSS), D41.G (VSS), D50.G (VSS), D51.G (VSS), D60.G (VSS), D61.G (VSS), D70.G (VSS), D71.G (VSS), DA1.G (VSS), DA2.G (VSS), DA3.G (VSS), DA4.G (VSS), J1.3, J2.3, J3.4, J4.4, J5.4, J6.4, R20.2, R21.2, SW1.2 ("~"), SW2.2 ("~"), SW3.2 ("~"), SW4.2 ("~"), SW5.2 ("~"), SW6.2 ("~"), SW7.2 ("~"), SW8.2 ("~"), SW9.2 ("~"), SW10.2 ("~"), SW11.2 ("~"), SW12.2 ("~"), SW13.2 ("~"), U1.3 (GND), U1.8 (GND), U1.13 (GND), U1.18 (GND), U1.23 (GND), U1.28 (GND), U1.33 (AGND), U1.38 (GND), U2.2 (GND), U2.3 (TEST), U3.4 (GND), U3.8 (DIR), USB1.1 (GND), USB1.12 (GND), USB1.13 (SHIELD)
unnamed: DA1.O (Out), DA2.I (In)
unnamed: DA2.O (Out), DA3.I (In)
unnamed: DA3.O (Out), DA4.I (In)
unnamed: SW13.1 ("~"), U1.1 (GPIO0)
unnamed: SW12.1 ("~"), U1.2 (GPIO1)
unnamed: SW7.1 ("~"), U1.4 (GPIO2)
unnamed: SW6.1 ("~"), U1.5 (GPIO3)
unnamed: SW5.1 ("~"), U1.6 (GPIO4)
unnamed: SW4.1 ("~"), U1.7 (GPIO5)
unnamed: SW3.1 ("~"), U1.9 (GPIO6)
unnamed: SW2.1 ("~"), U1.10 (GPIO7)
unnamed: SW1.1 ("~"), U1.11 (GPIO8)
unnamed: SW11.1 ("~"), U1.12 (GPIO9)
unnamed: SW10.1 ("~"), U1.14 (GPIO10)
unnamed: SW9.1 ("~"), U1.15 (GPIO11)
unnamed: SW8.1 ("~"), U1.16 (GPIO12)
unnamed: R1.2, U1.17 (GPIO13)
unnamed: R2.2, U1.34 (GPIO28_ADC2)
unnamed: U1.TP2 (USB1), USB1.5 (DN2), USB1.7 (DN1)
unnamed: U1.TP3 (USB2), USB1.6 (DP1), USB1.8 (DP2)
unnamed: U1.40 (VBUS), USB1.2 (VBUS), USB1.11 (VBUS)
unnamed: R20.1, USB1.4 (CC1)
unnamed: R21.1, USB1.10 (CC2)

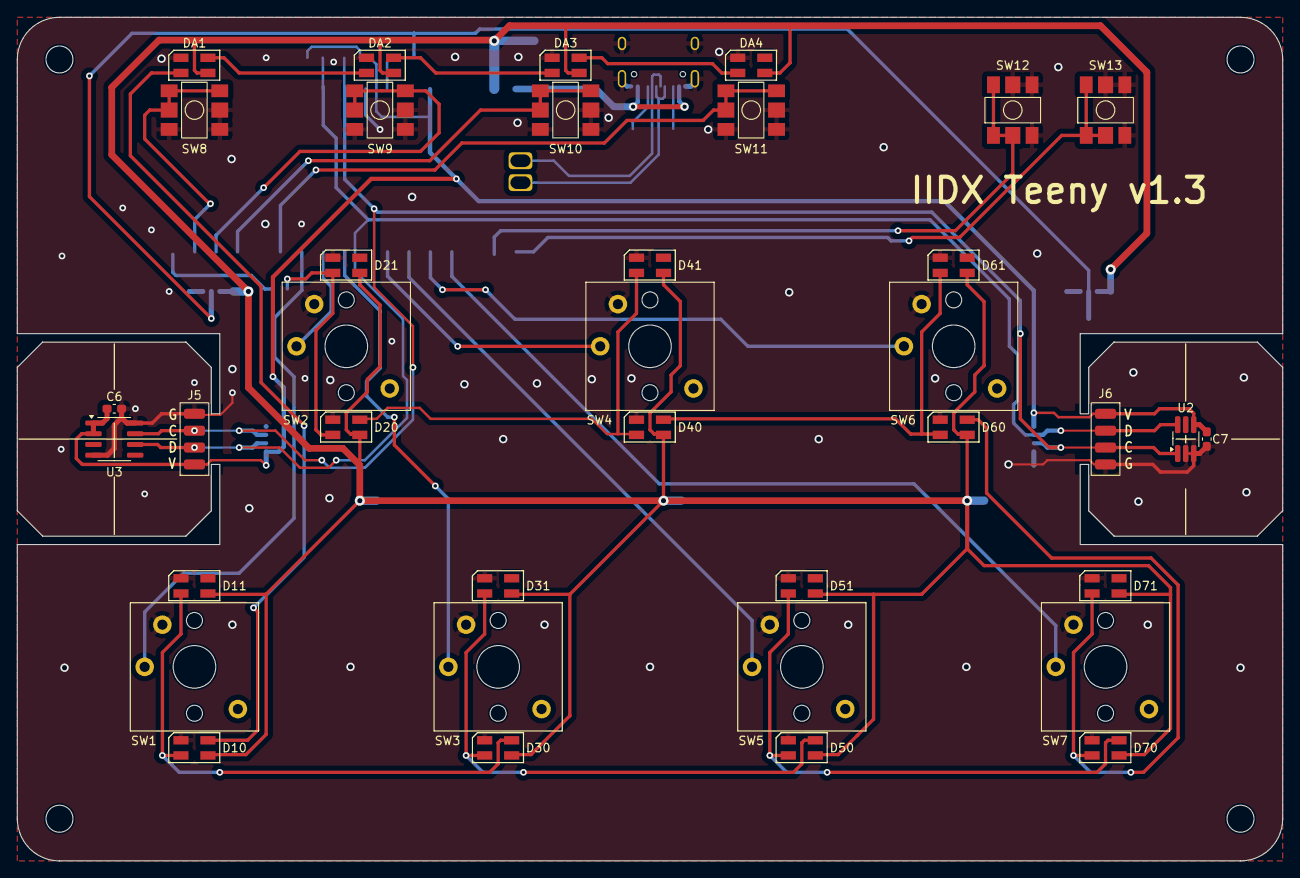
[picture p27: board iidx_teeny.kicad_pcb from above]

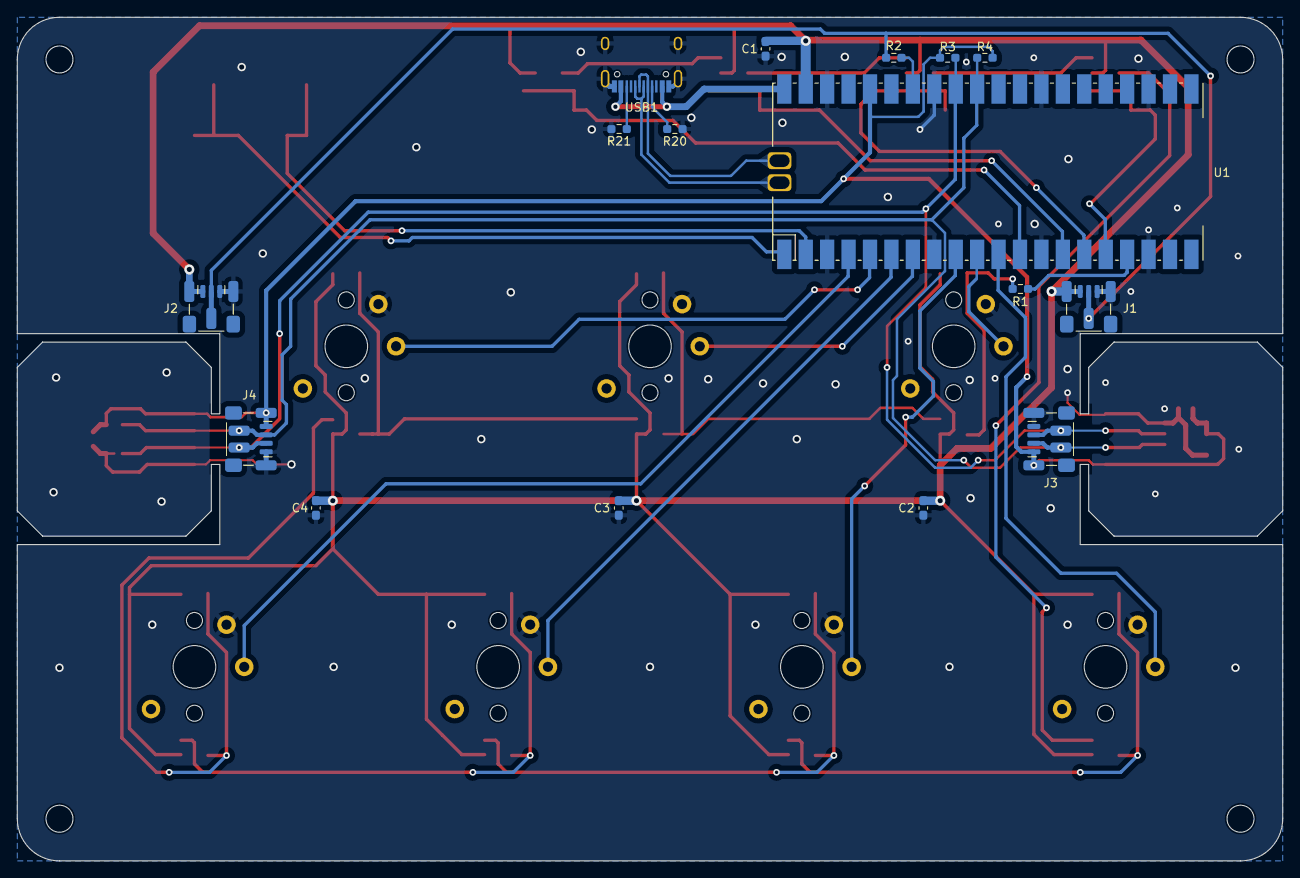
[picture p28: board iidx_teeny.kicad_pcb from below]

Board: 2 copper layers, 150.0 x 100.0 mm, 57 parts (16 on the bottom side), 37 nets.

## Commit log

2023-05-01 Cloned from pico iidx
    [Credit Button Assy (Groovy).step, EVQ-P1D05M.stp, J 2835.step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]
2023-05-01 Finished schematics and board shape
    [SKPMAM.STEP, iidx_keycap_main.scad, iidx_keycap_teeny.scad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]
2023-05-03 PCB and keyboard housing done
    [iidx_teeny.kicad_pcb, iidx_teeny.kicad_sch, iidx_teeny_logo.stl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]
2023-05-05 Start TT modeling
    [TT_base.scad, Teeny_TT_base.scad, iidx_teeny_logo.stl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]
2023-05-08 Fix top aux hole clearance issue
    [teeny_top.scad, teeny_top.stl]
2023-05-09 Finetune bottom
    [teeny_bottom.scad, teeny_bottom.stl]
2023-05-10 Finetune teeny top
    [teeny_top.scad, teeny_top.stl]
2023-05-11 PCB updated with two LEDs per button and larger Y gap
    [iidx_teeny.kicad_pcb, iidx_teeny.kicad_sch]
2023-05-11 Keycap updated, works well
    [iidx_keycap_teeny.scad, iidx_keycap_teeny.stl]
2023-05-14 Cad files update (working)
    [TTshaft.scad, Teeny_TT_base.scad, bearing_seat.scad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]
2023-05-21 3D files update to fit v1 PCB
    [iidx_keycap_teeny.scad, iidx_keycap_teeny_v1.stl, teeny_bottom.scad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]
2023-05-26 Better aux and set button frame
    [iidx_keycap_teeny_2.stl, iidx_keycap_teeny_3.stl, iidx_keycap_teeny_4.stl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]
2023-05-28 V1 validated, v0 removed
    [iidx_keycap_teeny.stl, teeny_bottom.stl, teeny_bottom_v1.stl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]
2023-05-31 Documentation update
    [iidx_keycap_teeny.scad, led_ring_reflector.scad, teeny_bottom.stl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]
2023-06-03 Better video cut
2023-07-23 Finetuned hinge cover
    [teeny_hinge_cover.stl, teeny_tt.scad]
2023-10-14 Crossreference to Mai Pico
2023-12-03 Upload the missing P2 bottom stl file
    [teeny_bottom_P2.stl]
2023-12-10 Fix minor BOM issue
2024-02-12 Update USB-C position for stable cable connection
    [iidx_teeny.kicad_pcb, teeny_bottom.scad, teeny_bottom_P1.stl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]
2024-10-28 PCB v1.2, easier soldering
    [iidx_teeny.kicad_pcb, iidx_teeny.kicad_sch]
2024-11-20 PCB v1.3 (sensors on board)
    [iidx_teeny.kicad_pcb, iidx_teeny.kicad_sch]
2024-11-20 Mention 1.2mm in gerber filename
2024-12-18 Freeze this repository with latest files
    [Keyboard Teeny - Base_1P.stl, Keyboard Teeny - Base_2P.stl, Keyboard Teeny - Panel.stl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]
2024-12-21 Use hex nut to fix disc seat and magnet seat
    [Turntable - Disc Seat.stl, Turntable - Magnet Seat.stl]
2025-01-15 Upload missing teeny disc STL
    [Turntable Teeny - Disc.stl]
